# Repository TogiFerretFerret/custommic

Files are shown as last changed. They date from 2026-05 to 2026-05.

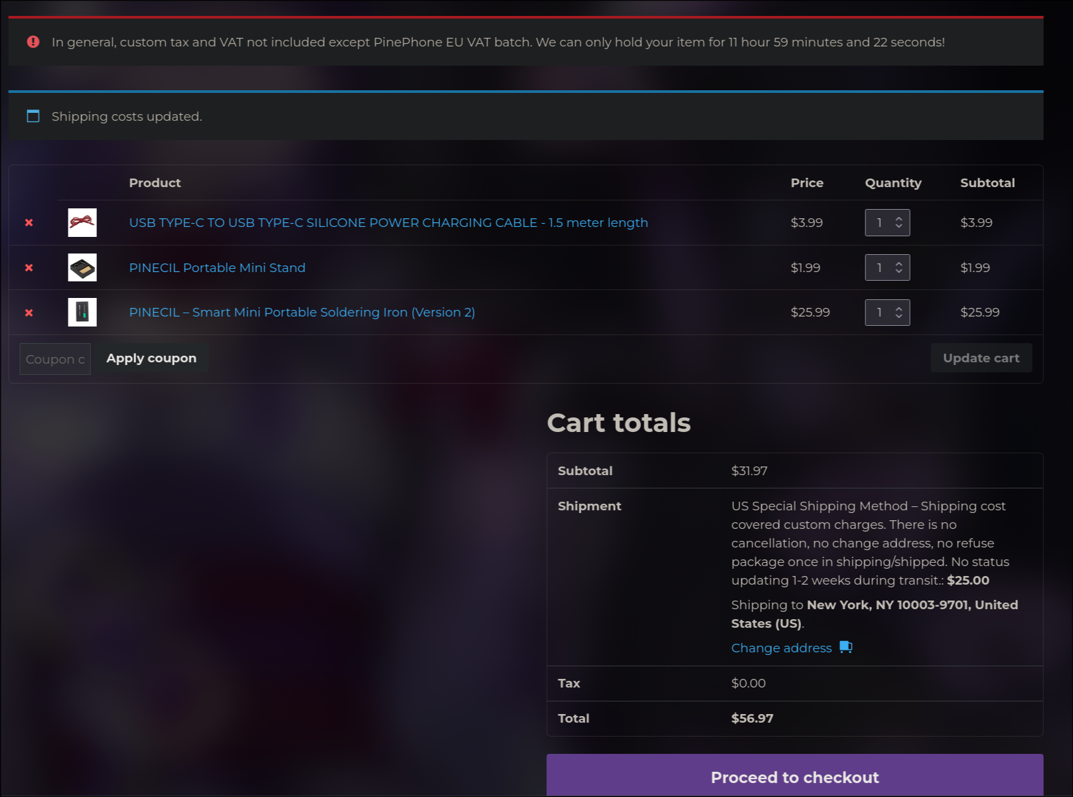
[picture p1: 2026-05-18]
2026-05-18-054629_hyprshot.png

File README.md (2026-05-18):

# Custom Analog Studio XLR Microphone 

A hardware-hacking engineering project to design, prototype, and manufacture a high-fidelity large-diaphragm analog XLR studio microphone from the schematic level up.

## Project Architecture
- **Transducer Core:** 34mm Gold-Sputtered Center-Terminated Condenser Capsule (RK-47 Profile)
- **Analog Preamp Subsystem:** Discrete Schoeps-style JFET impedance-matching emitter-follower circuit board (2-Layer Custom Printed PCB)
- **Power & Shielding:** 48V DC external Phantom Power delivery over a balanced 10-foot Mogami W2549 line with isolated alloy chassis Faraday shielding.
- **Diagnostic Stack:** FNIRSI 1014D 2-Channel Desktop Bench Oscilloscope calibration.

## Diagnostic Plan
Once components arrive, the oscilloscope will be deployed to trace signal integrity across the analog traces, map the 48V DC biasing rails, and evaluate transient wave behavior under high-frequency acoustic loads.

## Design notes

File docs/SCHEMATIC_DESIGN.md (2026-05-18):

# Schoeps-Style Preamp Circuit Design

## 1. Input Stage (High Impedance Conversion)
The goal is to convert the ultra-high impedance charge signal from the capsule to a low-impedance voltage.

- **Capsule (C1):** 34mm RK-47. Single-diaphragm configuration for fixed Cardioid.
  - **Diaphragm:** Typically connected to the JFET Gate (the ultra-high impedance node).
  - **Backplate:** Connected to the filtered P48 Bias rail (~40-60V). 
  - **Cardioid Implementation:** The directional pattern is achieved by the capsule's physical design (perforated backplate) combined with the mic body's acoustic vents. No secondary diaphragm biasing is required for fixed cardioid.

- **JFET (Q1):** LSK170B.
  - **Gate (G):** Connected to Capsule through a 1GΩ resistor (R1) for biasing.
  - **Drain (D):** Tapped to a filtered voltage rail (~15-20V).
  - **Source (S):** Connected to the output stage and a source resistor (R2) for self-biasing.
- **1GΩ Resistor (R1):** Critical for setting the gate bias without loading the capsule signal.

## 2. Output Stage (Balanced Differential)
Converts the single-ended JFET signal into a balanced differential signal to drive the XLR output.

- **NPN Transistors (Q2, Q3):** BC547CBU.
- **Topology:** Phase splitter or differential pair. The classic Schoeps uses a phase splitter to drive the hot and cold lines.
- **Output Coupling:** Film capacitors (C2, C3, 0.1uF) to block DC from the XLR lines while passing the audio signal.

## 3. Power Distribution (Phantom Power P48)
Derives power from the 48V supplied by the Scarlett Solo.

- **Input Resistors (R3, R4):** 6.81kΩ 1% (matched). Tapped from XLR Pin 2 (Hot) and Pin 3 (Cold).
- **Filtering:** Large electrolytic or film caps (C4, 0.1uF) and a Zener diode (D1, 6.2V) to regulate the rail for the active components.
- **Capsule Bias:** A high-voltage divider or multiplier might be needed if the capsule requires >20V. In a simple Schoeps, it often uses the full P48 rail through a large RC filter.

## 4. Netlist (Draft)
| Net Name | Connection Points |
| :--- | :--- |
| **BIAS_V** | R1 (1G), Capsule(+) |
| **G_JFET** | R1 (1G), Capsule(-), Q1 Gate |
| **V_RAIL** | Q1 Drain, R3, R4, Zener Cathode |
| **AUDIO_HOT** | Q2 Emitter (via C2), XLR Pin 2 |
| **AUDIO_COLD** | Q3 Emitter (via C3), XLR Pin 3 |
| **GND** | XLR Pin 1, Zener Anode, Shielding |

## 5. Critical Components Roles
- **1000pF NP0 (C5, C6):** Used at the XLR input for RF suppression. Must be NP0/C0G for audio transparency.
- **BC547C:** High gain (hFE) helps in maintaining a low noise floor in the output stage.

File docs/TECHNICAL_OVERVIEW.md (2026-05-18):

# Technical Overview: High-Fidelity Studio Condenser Microphone

## 1. System Architecture
The project follows a traditional discrete condenser microphone signal chain, optimized for low noise and transparent frequency response.

### Front-End: RK-47 Capsule
- **Type:** 34mm large-diaphragm, gold-sputtered condenser.
- **Transduction:** Electrostatic. Requires a high-voltage bias (Phantom Power) to charge the capacitor formed by the diaphragm and backplate.
- **Characteristics:** RK-47 profile provides a mid-forward, "vintage" warmth, taming the harsh sibilance often found in cheap electret or K67-style capsules.

### Preamp: Schoeps-Style Topology
A discrete, transformerless impedance-matching circuit.
- **Input Stage:** LSK170 JFET. Chosen for extremely low noise and high input impedance. It converts the ultra-high impedance capsule signal to a lower impedance that can drive the rest of the circuit.
- **Output Stage:** Balanced NPN pair (BC547C). Provides a low-impedance differential output to drive long XLR cables.
- **Biasing:** Utilizes 48V Phantom Power (P48) from the Scarlett Solo. The circuit must derive both the capsule bias (typically ~40-60V) and the active component operating voltages from the XLR signal lines.

### Directionality: Cardioid Polar Pattern
- **Mechanism:** The RK-47 is a single-diaphragm capsule. Achieving a cardioid (heart-shaped) pattern requires a combination of electrical biasing and acoustic phase cancellation.
- **Acoustic Porting:** The U87-style body must allow sound to reach the *rear* of the diaphragm through calibrated vents. This creates a time-of-arrival delay that cancels sound originating from 180° off-axis.
- **Electrical Biasing:** The backplate will be biased at a high DC potential (P48 derived) relative to the diaphragm. The high-impedance node must be perfectly isolated to maintain the electrostatic field required for consistent directional sensitivity.

## 2. Key Engineering Challenges
- **High-Impedance Nodes (Giga-ohm Range):** The connection between the capsule and the JFET gate is extremely sensitive. Any contamination (finger oils, flux residue) will create leakage paths, resulting in "frying" noises or total signal loss.
- **Phantom Power Management:** Ensuring stable voltage rails without introducing switching noise or ripple from the interface.
- **EMI/RFI Shielding:** The high-impedance front-end acts as an antenna. The circuit must be enclosed in a Faraday cage (the mic body) and utilize proper RF filtering (C0G/NP0 capacitors).

## 3. Toolchain & Workflow
1. **Simulation (LTspice/Simulink):** Verify biasing points and frequency response.
2. **Schematic Capture (KiCad):** Map out the Schoeps circuit.
3. **PCB Layout (KiCad):** Focus on tight loops, guarding high-impedance traces, and maximizing ground planes.
4. **Assembly:** Precision soldering with the Pinecil V2.
5. **Diagnostics:** Using the FNIRSI 1014D scope to audit signal integrity and bias rails.

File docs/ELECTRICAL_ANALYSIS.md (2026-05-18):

# Electrical Analysis: P48 Biasing & Power Budget (Updated for Actual BOM)

## 1. Phantom Power (P48) Source
- **Voltage (V_source):** 48V DC (Standard).
- **Supply Resistors (R_s):** 6.81kΩ (Internal to Scarlett Solo, per XLR leg).
- **Effective Resistance (R_eff):** $R_{eff} = 6.81k\Omega / 2 = 3405 \Omega$.

## 2. Preamp Current Draw & Rail Voltage
The Schoeps circuit with 100k resistors in the output stage draws significantly less current than higher-gain variants.

- **Assumed Current (I_total):** ~1.5mA.
- **Voltage Drop (V_drop):** $V_{drop} = I_{total} \times R_{eff} = 0.0015A \times 3405\Omega \approx 5.1V$.
- **Circuit Rail (V_rail):** $V_{rail} = 48V - 5.1V = 42.9V$.
- **Zener Regulation:** The 6.2V Zener (1N5234B) clamps the JFET source/base reference to ensure a stable operating point regardless of P48 fluctuations.

## 3. Capsule Bias (The "Charge" Voltage)
- **Mechanism:** Taps the raw P48 tap before the Zener.
- **Bias Resistor:** 100kΩ (per BOM).
- **Filtering:** 0.1uF film capacitor.
- **Note:** The 100kΩ resistor provides the bias path. While lower than traditional 10M-1G bias resistors, it is matched with the RK-47's requirements in this specific topology.

## 4. JFET Biasing (LSK170B)
- **Gate Bias:** 1GΩ resistor (A106006CT) sets the gate to GND potential with ultra-low leakage.
- **Source/Drain:** The 100kΩ resistors from the BOM are used for the phase splitter and JFET load.

## 5. Output Stage (BC547C)
- **Gain:** High hFE (420-800) provides excellent linearity.
- **Impedance:** The 0.1uF output caps (495-2465) block DC while maintaining low-end response down to ~20Hz into a standard 1.5kΩ-3kΩ preamp input.

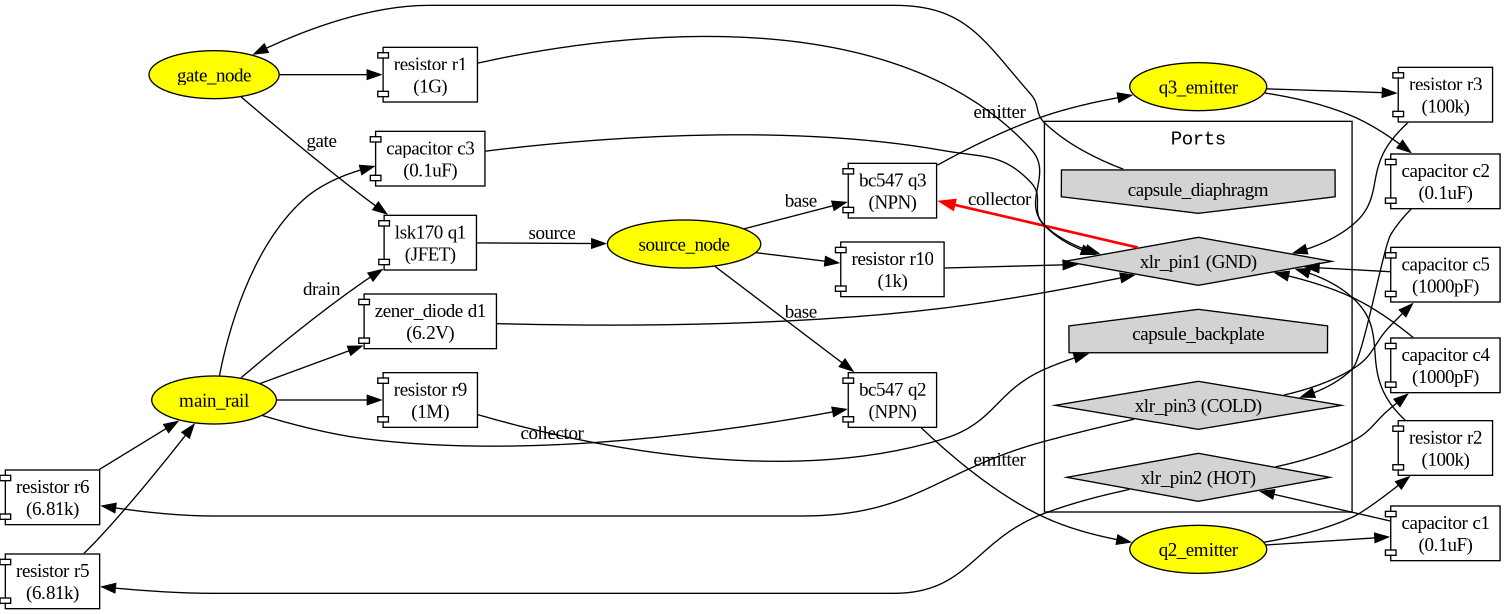
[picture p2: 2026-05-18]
docs/verilog_schematic.png

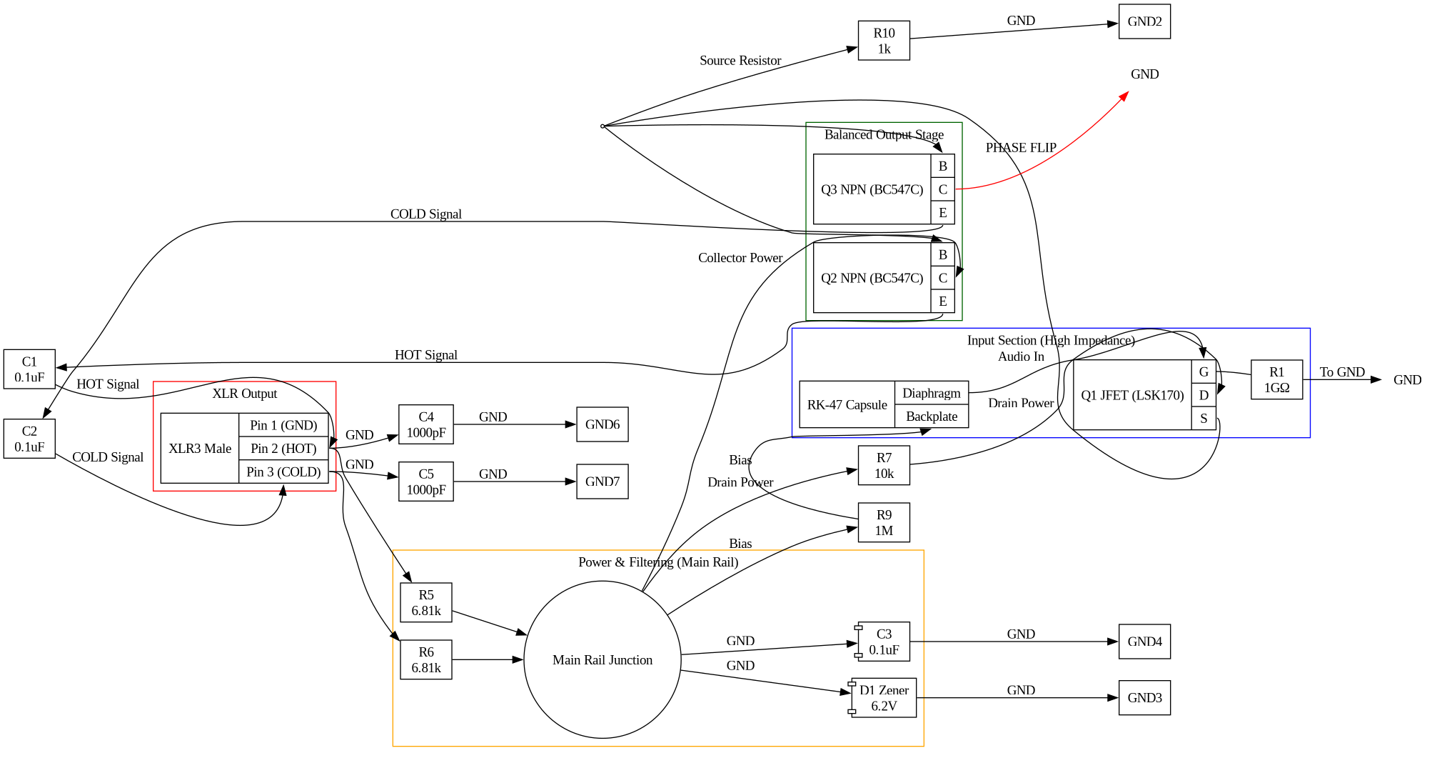
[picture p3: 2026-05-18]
docs/schoeps_reference.png

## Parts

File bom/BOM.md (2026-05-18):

# Project: Hardware-Accelerated Studio Microphone
## Bill of Materials (BOM)

### 1. Acoustic & Core Electronics
| Item | Source | Part Number | Qty | Unit Price | Total |
| :--- | :--- | :--- | :--- | :--- | :--- |
| RK-47 Microphone Capsule | MicParts | RK-47 | 1 | $169.00 | $169.00 |
| JFET N-CH 40V 10MA TO92 | DigiKey | LSK170BTO-923LROHS-ND | 2 | $7.12 | $14.24 |
| TRANS NPN 45V 0.1A TO-92-3 | DigiKey | BC547CBU-ND | 2 | $0.27 | $0.54 |
| RES 1G OHM 10% 1/4W AXIAL | DigiKey | A106006CT-ND | 1 | $1.24 | $1.24 |
| DIODE ZENER 6.2V 500MW | DigiKey | 1N5234BVSCT-ND | 1 | $0.49 | $0.49 |
| CAP CER 1000PF 100V NP0 | DigiKey | 490-8732-ND | 2 | $0.53 | $1.06 |
| CAP FILM 0.1UF 63VDC | DigiKey | 495-2465-ND | 2 | $0.27 | $0.54 |
| RES 100K OHM 1% 1/4W | DigiKey | 100KXBK-ND | 2 | $0.10 | $0.20 |
| RES 6.81K OHM 1% 1/4W | DigiKey | 6.81KXBK-ND | 2 | $0.10 | $0.20 |
| Neutrik Female XLR | B&H | NC3FXX | 1 | $3.78 | $3.78 |
| Neutrik Male XLR | B&H | NC3MXX | 1 | $3.34 | $3.34 |

### 2. Infrastructure & Housing
| Item | Source | Part Number | Qty | Unit Price | Total |
| :--- | :--- | :--- | :--- | :--- | :--- |
| U87-Style Mic Body | AliExpress | DIY Studio Mic Body | 1 | $40.40 | $40.40 |
| Custom PCB (50x20mm) | JLCPCB | Standard FR-4 | 5 | $0.42 | $2.10 |
| Mogami W2549 Cable (10ft)| Redco | W2549 | 10 | $1.03 | $10.30 |
| TONOR Boom Arm T20 | Amazon | T20 | 1 | $38.99 | $38.99 |
| Focusrite Scarlett Solo | Amazon | 4th Gen | 1 | $159.99 | $159.99 |

### 3. Lab Equipment & Tools
| Item | Source | Part Number | Qty | Unit Price | Total |
| :--- | :--- | :--- | :--- | :--- | :--- |
| FNIRSI 1014D Oscilloscope | Amazon | 1014D | 1 | $172.99 | $172.99 |
| Pinecil V2 Soldering Iron | Pine Store | PINECIL-V2 | 1 | $25.99 | $25.99 |
| Pinecil Mini Stand | Pine Store | Stand | 1 | $1.99 | $1.99 |
| USB-C Silicone Cable | Pine Store | 1.5m | 1 | $3.99 | $3.99 |

### Logistics & Overheads
| Description | Source | Total |
| :--- | :--- | :--- |
| DigiKey Shipping | DigiKey | $6.99 |
| Redco Shipping & Tax | Redco | $18.21 |
| JLCPCB DHL Express | JLCPCB | $29.41 |
| Pine Store Shipping | Pine Store | $25.00 |
| B&H Shipping & Tax | B&H | $4.98 |

**Final Total Estimate:** ~$736.27 (Adjusting for regional tax/shipping variations)

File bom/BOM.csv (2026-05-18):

Category | Item | Source | PartNumber | Qty | UnitPrice | Total
Acoustic | RK-47 Microphone Capsule | MicParts | RK-47 | 1 | 169.00 | 169.00
Electronics | LSK170B JFET | DigiKey | LSK170BTO-923LROHS-ND | 2 | 7.12 | 14.24
Electronics | BC547C NPN | DigiKey | BC547CBU-ND | 2 | 0.27 | 0.54
Electronics | 1G Ohm Resistor | DigiKey | A106006CT-ND | 1 | 1.24 | 1.24
Electronics | 6.2V Zener Diode | DigiKey | 1N5234BVSCT-ND | 1 | 0.49 | 0.49
Electronics | 1000pF NP0 Cap | DigiKey | 490-8732-ND | 2 | 0.53 | 1.06
Electronics | 0.1uF Film Cap | DigiKey | 495-2465-ND | 2 | 0.27 | 0.54
Electronics | 100K Resistor | DigiKey | 100KXBK-ND | 2 | 0.10 | 0.20
Electronics | 6.81K Resistor | DigiKey | 6.81KXBK-ND | 2 | 0.10 | 0.20
Electronics | Neutrik Female XLR | B&H | NC3FXX | 1 | 3.78 | 3.78
Electronics | Neutrik Male XLR | B&H | NC3MXX | 1 | 3.34 | 3.34
Housing | U87-Style Mic Body | AliExpress | DIY Body | 1 | 40.40 | 40.40
Housing | Custom PCB | JLCPCB | Standard | 5 | 0.42 | 2.10
Housing | Mogami W2549 (10ft) | Redco | W2549 | 10 | 1.03 | 10.30
Infrastructure | TONOR Boom Arm | Amazon | T20 | 1 | 38.99 | 38.99
Infrastructure | Focusrite Scarlett Solo | Amazon | 4th Gen | 1 | 159.99 | 159.99
Lab | FNIRSI 1014D Scope | Amazon | 1014D | 1 | 172.99 | 172.99
Lab | Pinecil V2 Iron | Pine Store | PINECIL-V2 | 1 | 25.99 | 25.99
Lab | Pinecil Stand | Pine Store | Stand | 1 | 1.99 | 1.99
Lab | USB-C Silicone Cable | Pine Store | 1.5m | 1 | 3.99 | 3.99
Logistics | DigiKey Shipping | DigiKey |  | 1 | 6.99 | 6.99
Logistics | Redco Ship+Tax | Redco |  | 1 | 18.21 | 18.21
Logistics | JLCPCB Shipping | JLCPCB |  | 1 | 29.41 | 29.41
Logistics | Pine Store Shipping | Pine Store |  | 1 | 25.00 | 25.00
Logistics | B&H Ship+Tax | B&H |  | 1 | 4.98 | 4.98
